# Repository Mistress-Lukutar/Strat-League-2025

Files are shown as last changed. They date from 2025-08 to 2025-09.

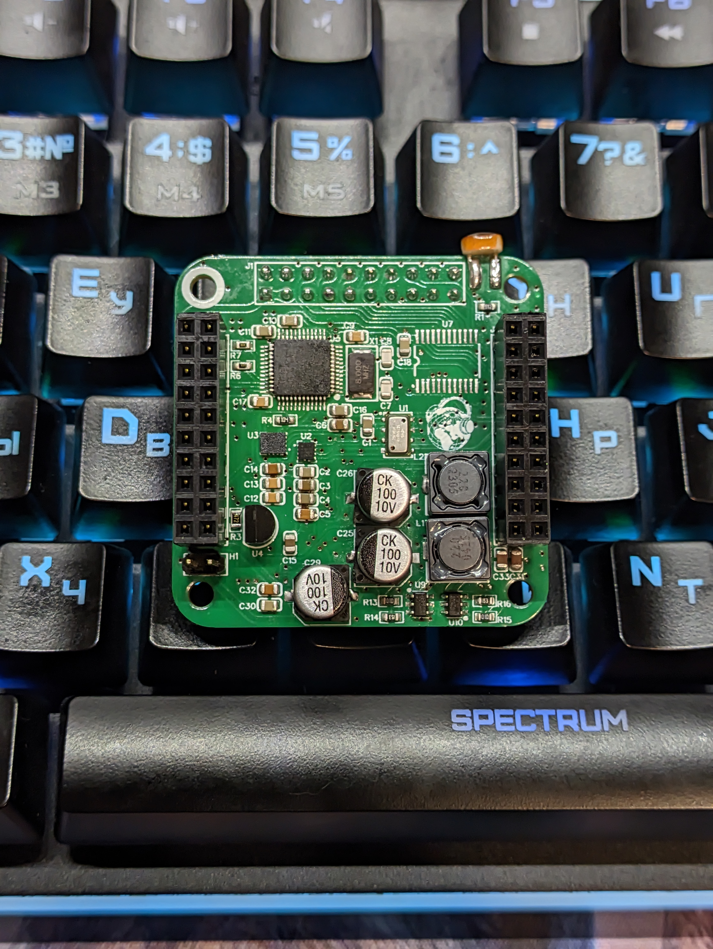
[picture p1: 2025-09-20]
Photos/PCB/IMU.jpg

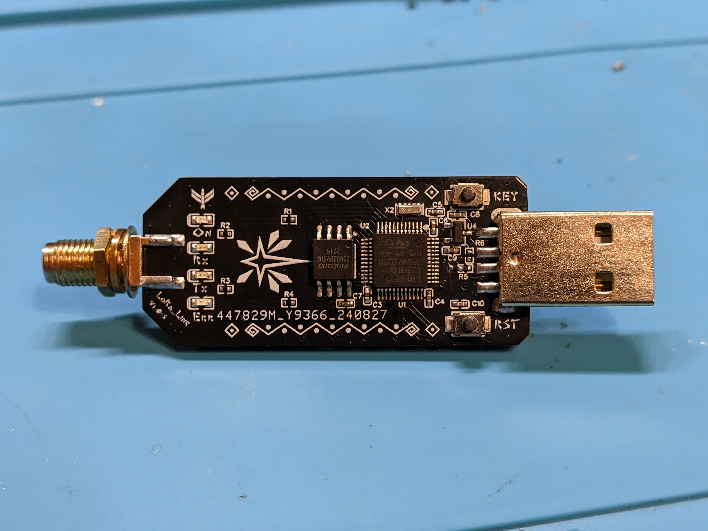
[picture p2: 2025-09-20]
Photos/PCB/LoRa Link.jpg

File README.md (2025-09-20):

# 🚀 Strat-League-2025: Sporadic Team Project

**Команда Sporadic | Курск**

Добро пожаловать в репозиторий стратосферного эксперимента по исследованию эффективности наночастиц в области технологий защиты от космической радиации!

## 📖 О проекте

Наш стратосферный аппарат предназначен для измерения радиационного фона на высоте и оценки защитных свойств различных материалов с наночастицами. Используя четыре сцинтилляционных датчика с разными типами защитных корпусов, мы исследуем, как материалы влияют на регистрацию космической радиации в условиях стратосферы.

### 🎯 Цель исследования

Проверить гипотезу о том, что различные материалы корпусов по-разному защищают от радиационного излучения. Датчик без защиты должен зафиксировать максимальный поток радиации, в то время как защищенные датчики покажут меньшее количество импульсов.

## 👥 Команда Sporadic

Мы — команда энтузиастов из Курска, участвующая во всероссийской программе "Стратосферный спутник". Наш проект объединяет в себе радиоэлектронику, программирование, 3D-моделирование и научные исследования.

> *Забавный факт: весь проект был разработан и реализован чуть больше чем за месяц! От идеи до готового аппарата — рекордные сроки для стратосферного эксперимента* ⚡

### Контакты 
Email: oppp032@gmail.com

Telegram: @the_real_crypto_schizo

## 🛠 Техническая платформа

- **Основа**: платы на базе STM32F4 — надежная и производительная платформа для различных применений
- **Датчики**: сцинтилляционные детекторы частиц, IMU  включающий в себя барометр `MS5611`, 6-DOF `LSM6DS3`, магнитометр `LIS3MDL`
- **Обработка**: плата `RadCounterX4` собственной разработки
- **Связь**: модуль приема телеметрии для ПК `LoRa_Link` собственной разработки, который доказал свою эффективность в нескольких страто- и тропосферных запусках

## 📁 Содержимое репозитория

```
📦 Strat-League-2025/
├── 🏗️ СAD/                 # 3D модели корпуса и креплений
├── ⚡ PCB/                 # Схемы и платы
├── 📚 DOC/                 # Документация, отчеты, презентации
└── 🖼️ Photos/              # Фотографии аппарата и компонентов
```

## 🔗 Связанные репозитории

### Основной код проекта
- **Полная версия**: [CanSat-Regular-HZ](https://github.com/Mistress-Lukutar/CanSat-Regular-HZ/tree/feature/strat2025) - финальный код для стратосферного полета (ветка `/feature/strat2025`)
- **История разработки**: [Project Insights](https://github.com/users/Mistress-Lukutar/projects/1/insights?period=max) - GitHub проект с логами разработки

## 🌟 Особенности проекта

- ✨ **Инновационный подход**: использование наночастиц для радиационной защиты
- 🔬 **Научная ценность**: реальные данные о поведении материалов в стратосфере  
- ⚙️ **Собственные решения**: плата `RadCounterX4` разработана с нуля
- 🚀 **Готовность к полету**: ~~за сутки до запусков~~ полностью протестированный и откалиброванный аппарат

## 🎯 Практическое применение

Результаты исследования могут найти применение в:
- Разработке систем радиационной защиты для космических аппаратов
- Создании защитного оборудования и снаряжения для пилотов
- Исследованиях воздействия космической радиации на материалы
- Образовательных программах по космической технике

## 📊 Результаты

После проведения эксперимента здесь будут представлены:
- Данные с четырех сцинтилляционных датчиков
- Анализ эффективности различных защитных материалов
- Графики изменения радиационного фона по высоте
- Выводы и рекомендации для дальнейших исследований

## 🤝 Участие в программе

Проект выполнен в рамках всероссийской программы "Стратосферный спутник" - уникальной образовательной инициативы, дающей молодым исследователям возможность проводить настоящие научные эксперименты в стратосфере.

---

**Команда Sporadic** • Курск • 2025

*Превращаем идеи в космические эксперименты за рекордные сроки!* 🚀✨

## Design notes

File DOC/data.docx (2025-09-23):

Задание для команд всероссийской программы “Стратосферный спутник”

Начиная с сезона 2025 года на сайте https://stratosputnik.ru/ будет формироваться специальный раздел с информацией об экспериментах всех команд, участвующих в программе. Этот раздел поможет будущим участникам этой и других программ придумывать новые эксперименты, позволит учиться на чужих ошибках и перенимать удачные решения.

Каждая команда обязана подготовить текст для размещения на сайте в соответствии с этим заданием!

Часть 1 (заполняется до запуска)

№ п\п | О чем необходимо написать | Требования к тексту | Ответ
1 | Полное наименование проекта | Без ограничений | Стратосферный аппарат для оценки эффективности наночастиц в области технологий защиты от космической радиации
2 | Явление (технология, объект…), которое исследовала команда | Только наименование явления, технологии, объекта… | Радиационное излучение
3 | Гипотеза: ваше предположение о том, как повлияют условия стратосферы на явление или объект, что будет происходить на аппарате во время запуска | 1 предложение | Четыре сцинтилляционных датчика, поднятые в стратосферу, покажут разное количество импульсов в зависимости от материала корпуса. Датчик без защиты зафиксирует максимальный поток радиации (больше всего импульсов), остальные же покажут меньшее число импульсов благодаря защите.
4 | Методика проведения исследования. Необходимо указать 1) условия проведения эксперимента (на какой высоте, в какое время вы его проводите), 2) последовательность операций на аппарате, благодаря которым происходит эксперимент и измеряются его результаты. | Условия проведения эксперимента - 1 предложение. Алгоритм проведения эксперимента, по 1 предложению на каждую операцию Например: Эксперимент проводится каждые 5000 м, отметки высоты определяется по данным барометра 1. Включение нагрева нихромовой нити с помощью реле 2. Регистрация водорода с помощью датчика MQ-8 3. Выключение нагрева | Эксперимент проводится весь полет начиная от команды «START» до ручного отключения оператором. Последовательность операций следующая Сброс счетчиков ЦИКЛ: Ожидание 100мс (В этот момент счетчики накапливают импульсы от сцинтилляторов) Подача импульса записи показаний счетчика в регистры Сброс счетчиков Последовательное чтение регистров (В этот момент МК имеет данные о количестве частиц, пойманных четырьмя датчиками) Перейти к ЦИКЛ
5 | Список датчиков, электронных модулей и устройств в составе полезной нагрузки (если вы самостоятельно изготавливали платы и электрические модули, кратко опишите принцип их работы) | Список наименований и типов модулей Например: - DS18B20 - термодатчик; - DS1115 - аналогово-цифровой преобразователь | Сцинтилляторы, полученные от партнеров – устройство способное регистрировать заряженные частицы используя сцинтилляционный эффект. Прибор выдает один короткий импульс при регистрации частицы. Модуль RadConterX4 собственной разработки, представляющий собой печатный узел, содержащий 4 счетчика для накопления импульсов от сцинтилляторов, сдвиговый регистр и декодер для выбора счетчика и получения его значения. Исходные файлы представлены в репозитории файлов проекта в папке PCB

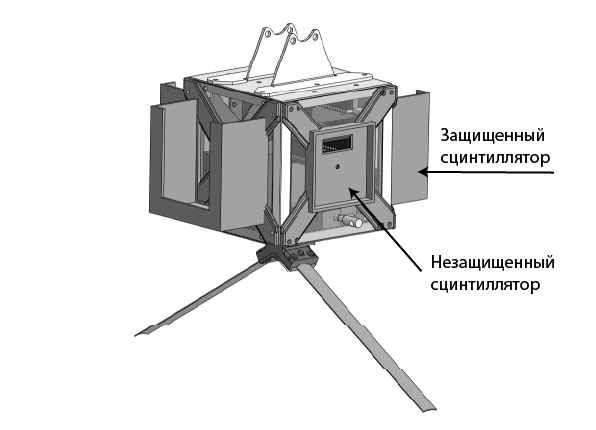
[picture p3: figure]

6 | Схема полезной нагрузки, показывающая принцип ее работы (например, если на аппарате есть механизмы, схема должна объяснять их работу) | Изображение в хорошем разрешении с подписями и, если требуется, кратким пояснением (1-2 предложения) | На рисунке изображены посадочные места под сцинтилляционные датчики – один не защищен материалом с наночастицами, другие – под защитой

Часть 2 (заполняется после запуска и анализа данных)

| О чем необходимо написать | Требования к тексту | Ответ
7 | Какие части ПН правильно работали во время запуска | Не более 60 слов | Работало исправно - Главный контроллер - IMU (Инерциальный измерительный блок) - Сцинтилляторы - Плата захвата RadCounterX4 - Регулятор температуры АКБ - "Черный ящик" (SD и EEPROM)
8 | Какие части ПН неправильно работали во время запуска или не работали. Предполагаемая причина отказа | Не более 60 слов | Возникли проблемы - Связь LoRa: потеряна на высоте около 3 км. - Вероятные причины: несовершенство конструкции антенны и помехи от наземных глушилок на частоте 433 МГц. - GPS: не работал на всём протяжении полёта. - Причина: сильное воздействие наземных глушилок.

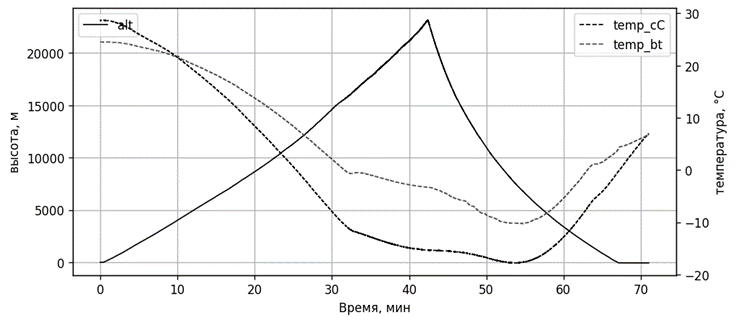
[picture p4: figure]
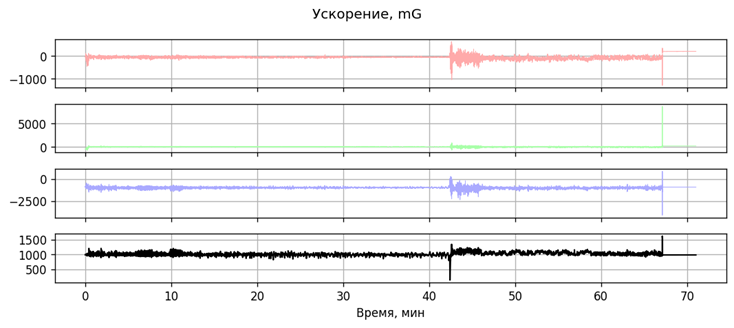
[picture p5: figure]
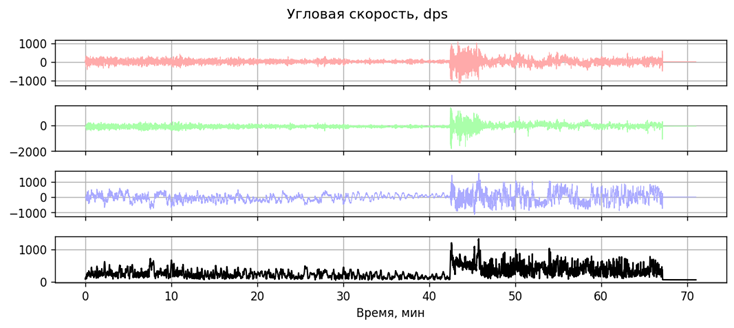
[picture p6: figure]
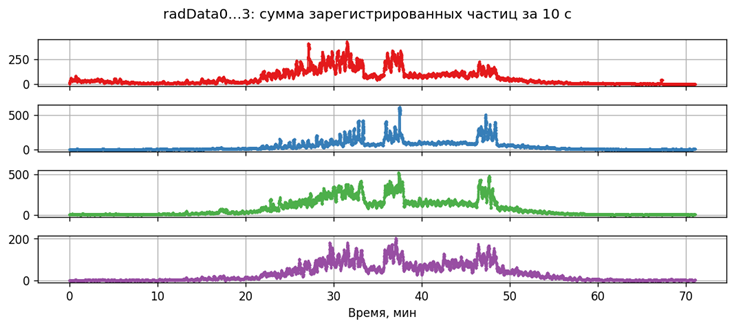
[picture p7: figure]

9 | Результат исследования, научный вывод: подтверждение или опровержение сформулированной ранее гипотезы | Не более 60 слов | Данные полученные бортовой электроникой Temp_cC – температура электроники, temp_bt - температура АКБ Здесь 3 цвета – оси XYZ, черная линия – модуль (усреднен) Экспериментально подтвердили гипотезу – материалы с наночастицами действительно защитили датчики от радиации. Максимальный фон был зарегистрирован датчиком без защиты (канал 2, > 500 событий пиковое значение), минимальный – с защитой с использованием CaO_2 (канал 4, до 200 событий)
10 | Финальный (лётный) программный код | Ссылка на Google/Яндекс Диск с открытым для просмотра доступом! По ссылке должен находиться исходный код в текстовом файле формата “.txt” | GitHub проект с логами разработки: https://github.com/users/Mistress-Lukutar/projects/1/insights?period=max Полный код проекта: https://github.com/Mistress-Lukutar/CanSat-Regular-HZ/tree/feature/strat2025 Репозиторий файлов проекта: https://github.com/Mistress-Lukutar/Strat-League-2025

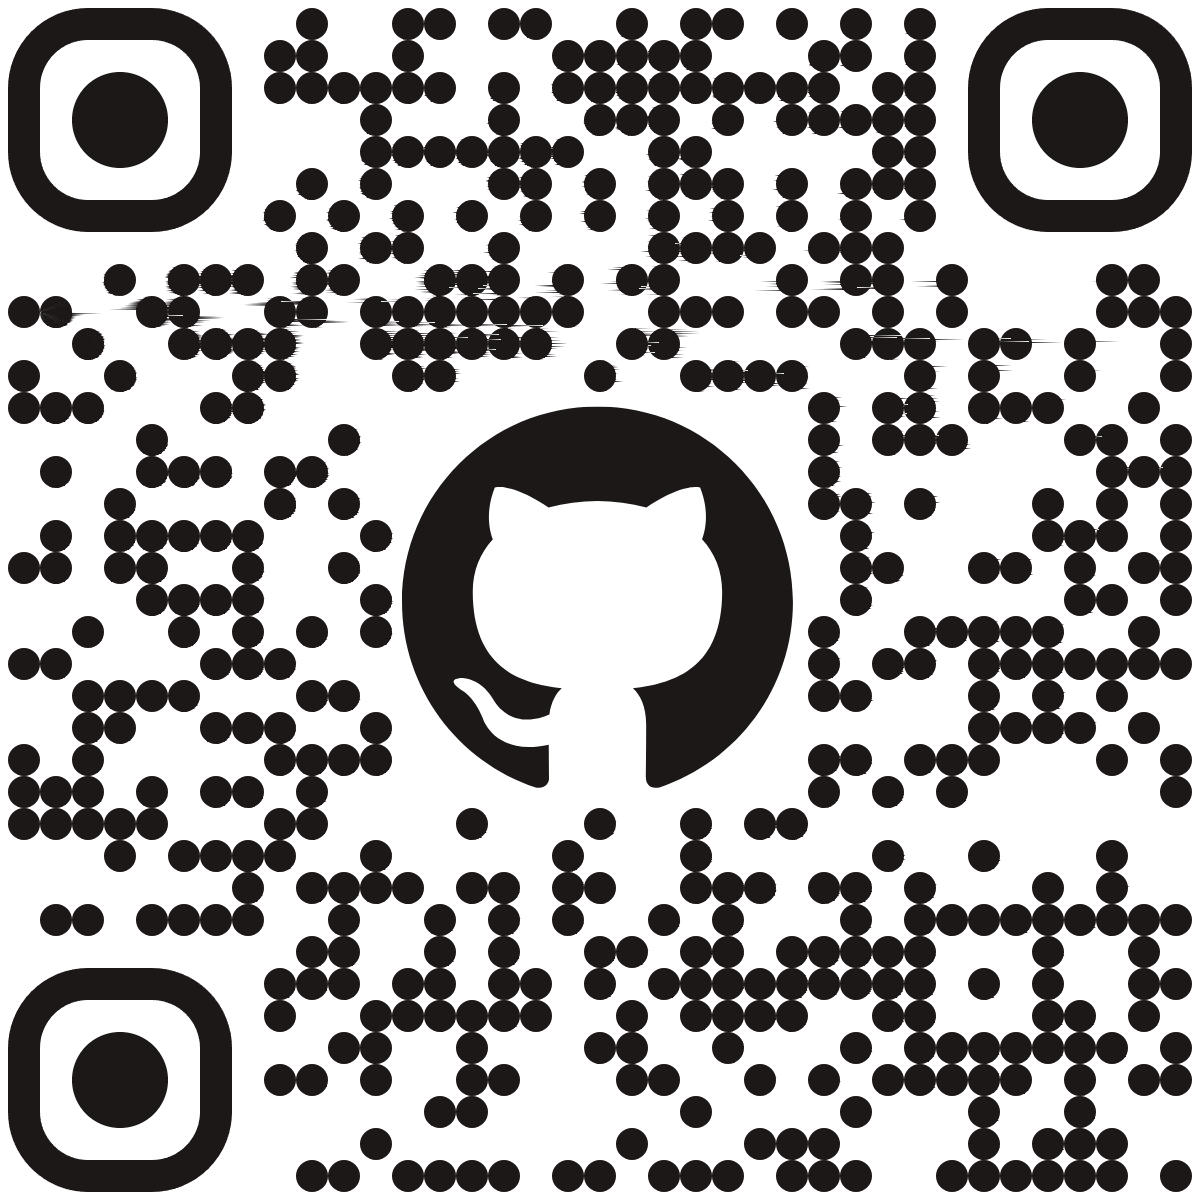
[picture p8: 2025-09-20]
DOC/Flyer/QR.png

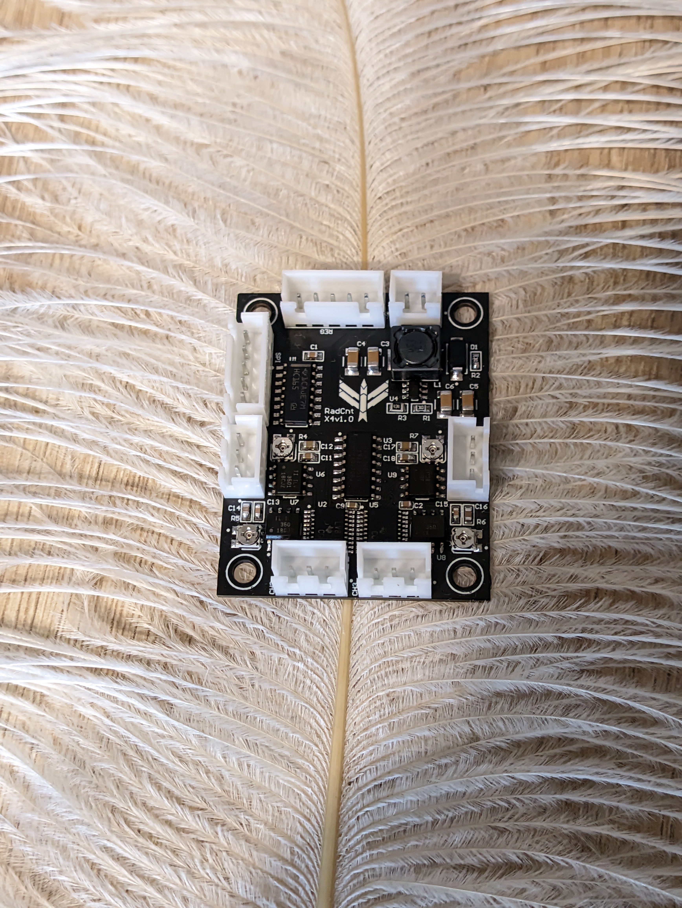
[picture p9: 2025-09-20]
Photos/PCB/RadCounterX4.jpg

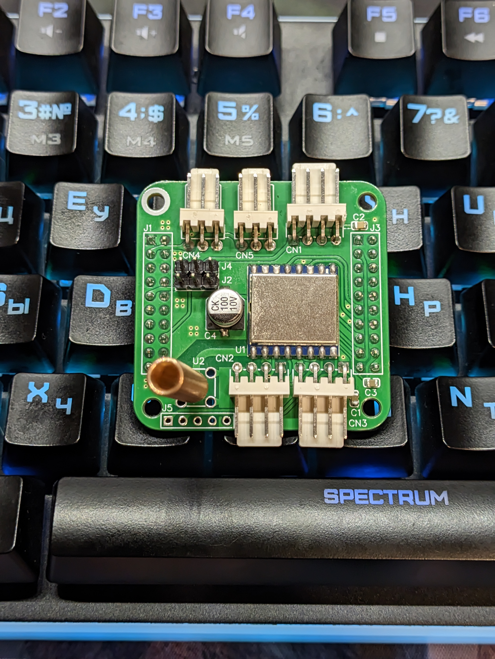
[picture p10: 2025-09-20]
Photos/PCB/Radio.jpg

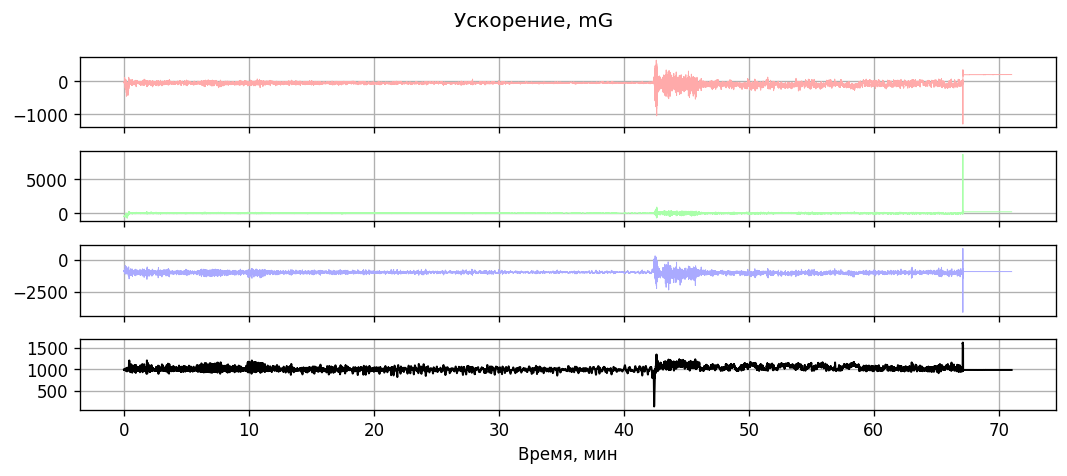
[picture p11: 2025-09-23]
Photos/plots/02_accel_4subplots.png

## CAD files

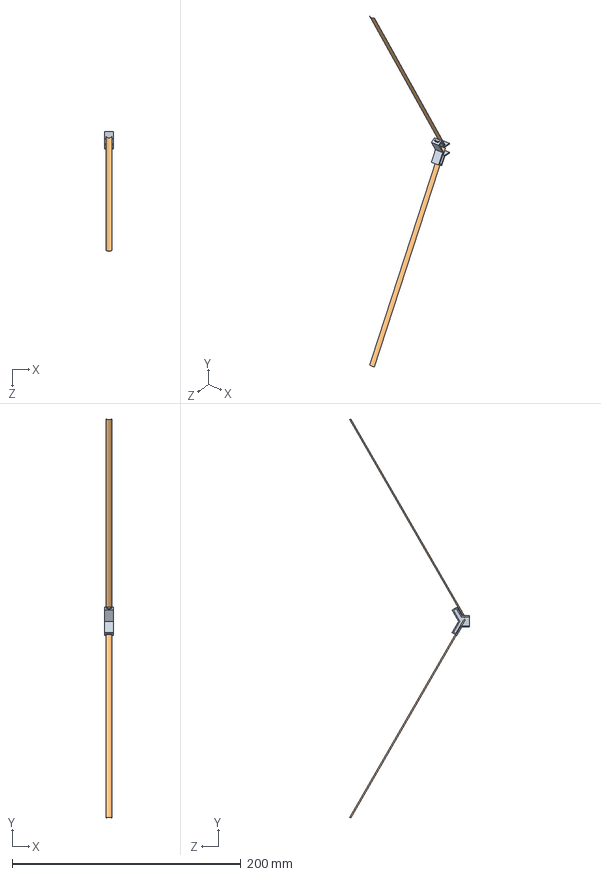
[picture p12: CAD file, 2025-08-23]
CAD/SolidWorks_release/Antenna/Ant.SLDASM
8.00 x 348.9 x 104.6 mm
Element x 2
Holder

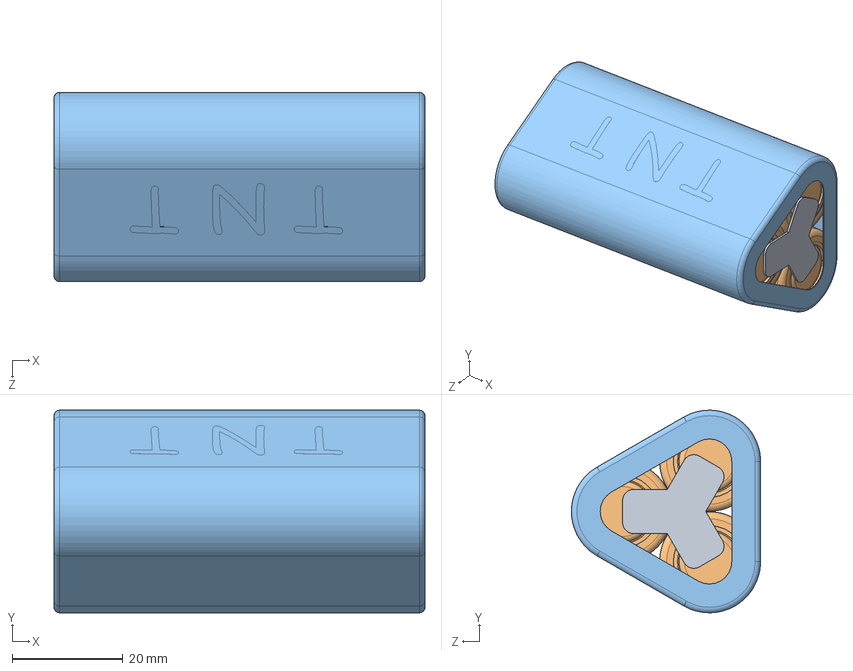
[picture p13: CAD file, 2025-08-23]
CAD/SolidWorks_release/BAT/Battery Pack.SLDASM
67.0 x 36.6 x 34.2 mm
PVC Battery Tube
Generic Li Ion 1850 cell x 3
Contact x 2

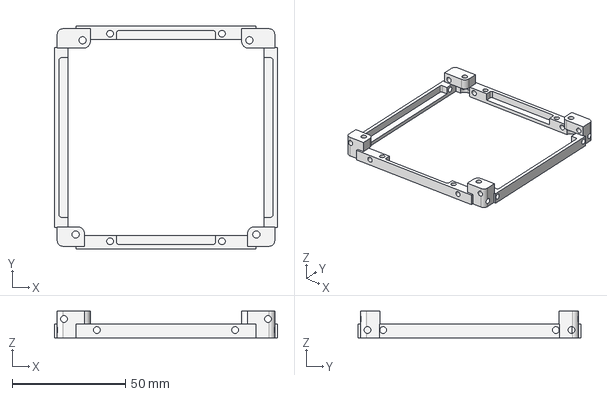
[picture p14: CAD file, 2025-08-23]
CAD/Export/Step/Frame Top.stp
98.4 x 98.4 x 11.7 mm

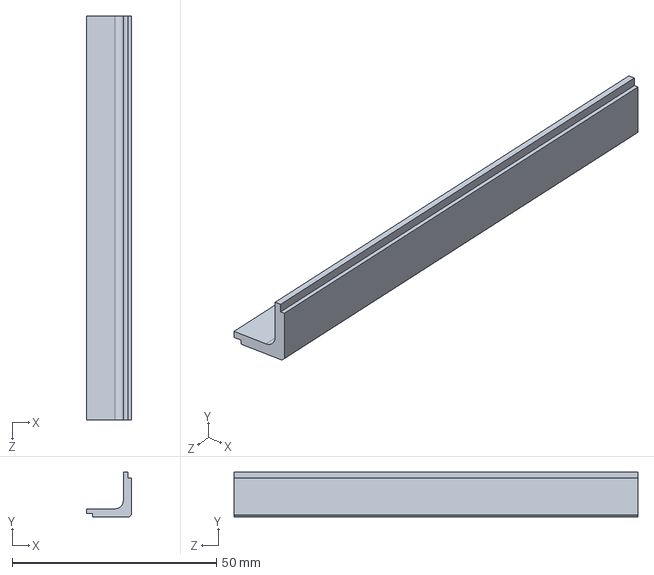
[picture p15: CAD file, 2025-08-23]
CAD/SolidWorks_release/CubeSat/Border.SLDPRT
11.0 x 11.0 x 99.0 mm

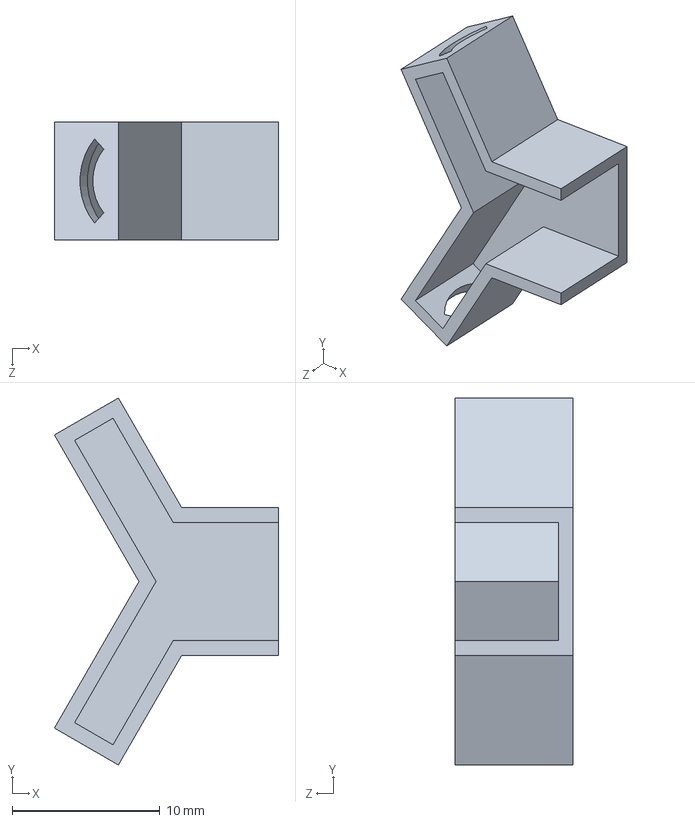
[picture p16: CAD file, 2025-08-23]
CAD/SolidWorks_release/Antenna/Holder.SLDPRT
15.2 x 24.8 x 8.00 mm

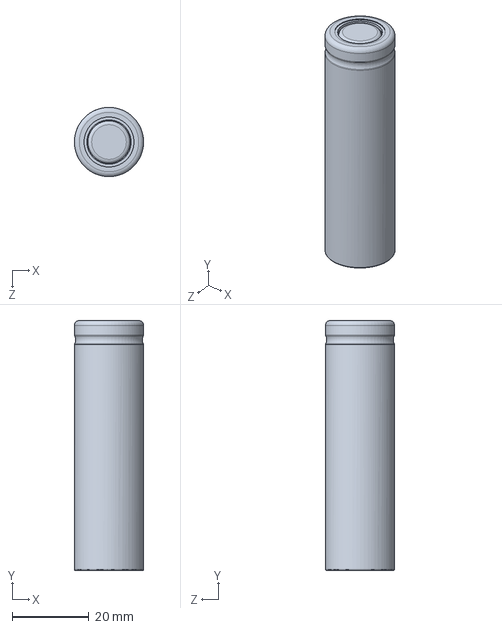
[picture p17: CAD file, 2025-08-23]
CAD/SolidWorks_release/BAT/Generic Li Ion 1850 cell.SLDPRT
18.0 x 65.0 x 18.0 mm

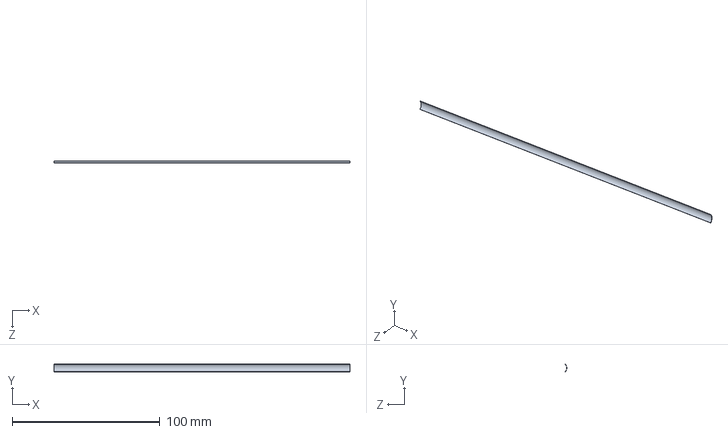
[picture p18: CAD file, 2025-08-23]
CAD/SolidWorks_release/Antenna/Element.SLDPRT
200.0 x 5.28 x 1.20 mm

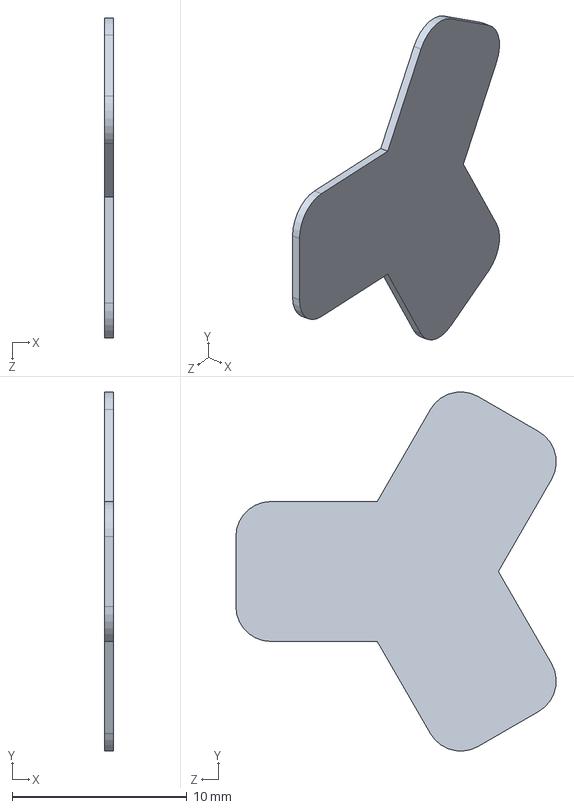
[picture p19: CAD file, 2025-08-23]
CAD/SolidWorks_release/BAT/Contact.SLDPRT
0.5 x 20.5 x 18.3 mm

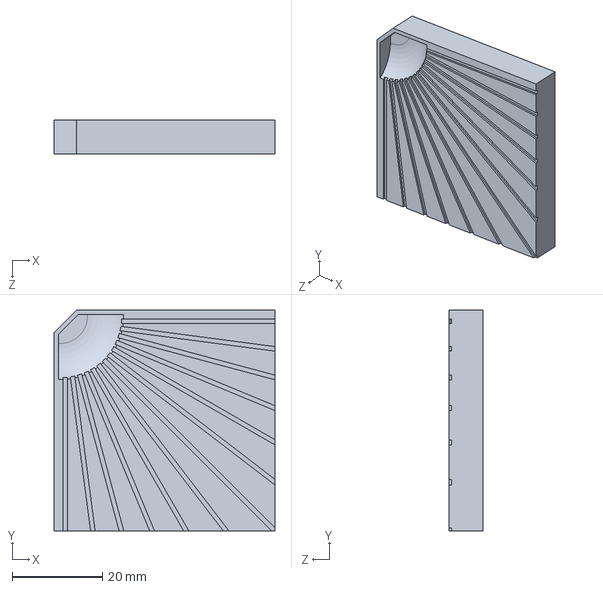
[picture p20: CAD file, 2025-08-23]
CAD/SolidWorks_release/Sensor/Base.SLDPRT
49.0 x 49.0 x 7.50 mm

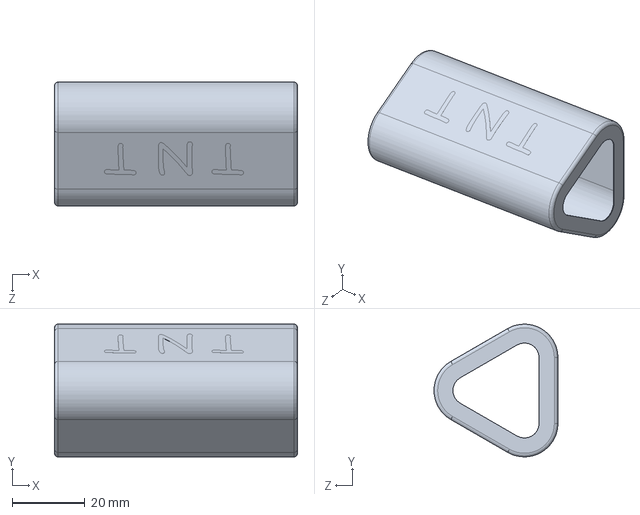
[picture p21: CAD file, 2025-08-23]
CAD/SolidWorks_release/BAT/PVC Battery Tube.SLDPRT
67.0 x 36.6 x 34.2 mm

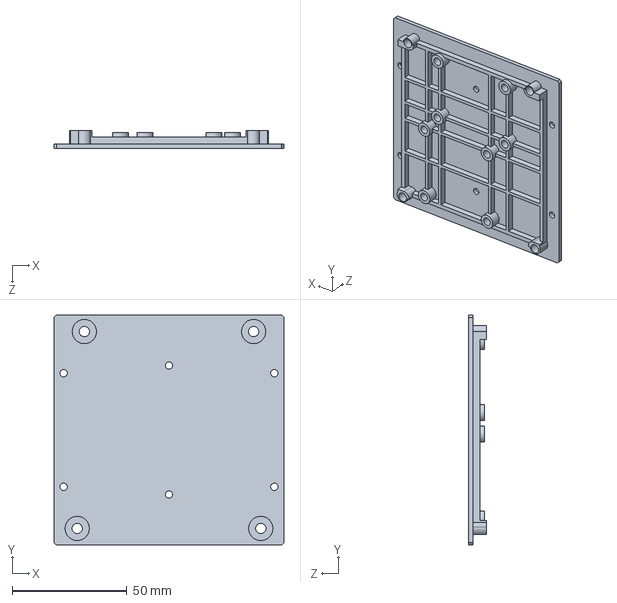
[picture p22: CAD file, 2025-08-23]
CAD/SolidWorks_release/CubeSat/Cover.SLDPRT
100.0 x 100.0 x 7.80 mm

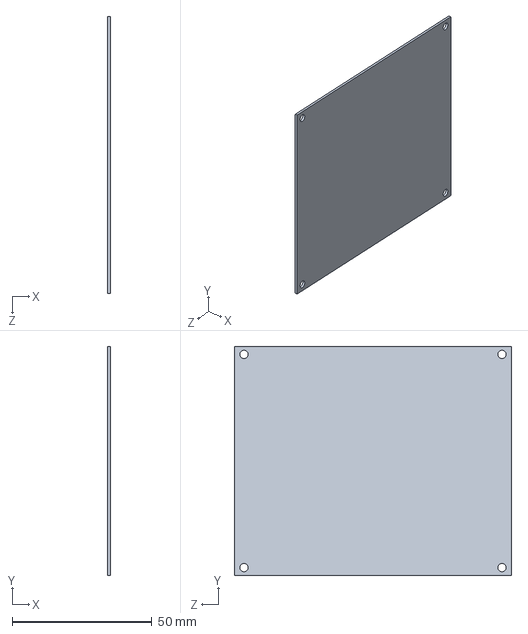
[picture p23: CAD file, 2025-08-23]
CAD/SolidWorks_release/CubeSat/Wall.SLDPRT
1.00 x 82.0 x 99.0 mm

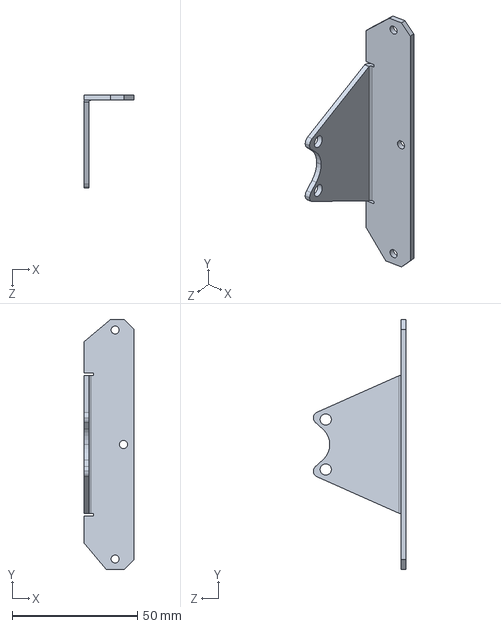
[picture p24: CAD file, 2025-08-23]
CAD/SolidWorks_release/CubeSat/Balloon Mount.SLDPRT
20.0 x 100.0 x 37.0 mm

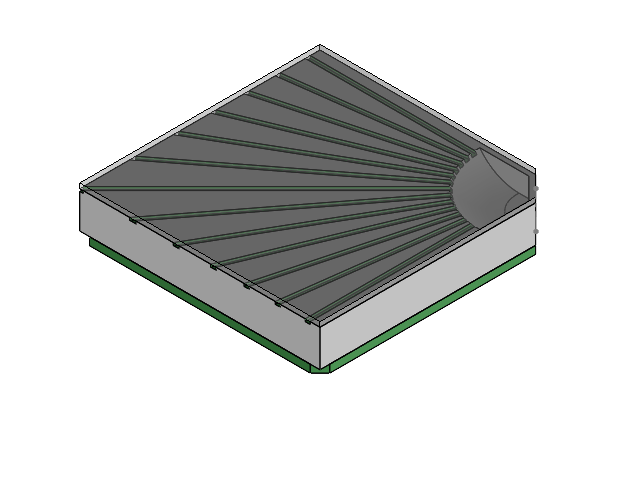
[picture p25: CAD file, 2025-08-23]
CAD/SolidWorks_release/Sensor/Sensor.SLDASM
Base
Glass
PCB
socket button head cap screw_am

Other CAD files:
CAD/SolidWorks_release/Sensor/Glass.SLDPRT
CAD/SolidWorks_release/CubeSat/Frame.SLDPRT
CAD/SolidWorks_release/CubeSat/RHZ Insert.SLDPRT
CAD/SolidWorks_release/Sensor/PCB.SLDPRT
CAD/Archive/Bobyshka_dlya_antenn18_svoya.stp
CAD/Archive/Generic Li Ion 1850 cell.step
CAD/Archive/Korpus_RBL.stp
CAD/Archive/M3 insert nut brass.STEP
CAD/Archive/Sborka_bloka_plat.stp
CAD/Archive/nasha_polnaya_sborka_21.stp
CAD/Export/parasolid/Detal.x_t
CAD/Export/parasolid/bobishka dlya antenn.x_t
CAD/Export/parasolid/dno s akb.x_t
CAD/Export/parasolid/krepesh scintilatora 1.x_t
CAD/Export/parasolid/krepesh scintilatora 2.x_t
CAD/Export/parasolid/krishka s kreplenyem shara.x_t
CAD/Export/parasolid/ugolok 22.x_t
CAD/Export/parasolid/ugolok12.x_t
CAD/SolidWorks_release/CubeSat/M3 insert nut.SLDPRT

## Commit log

2025-07-24 Set up on track DOC & CAD folders
2025-07-24 Updated description in PCB
2025-07-27 added valid CAD folder structure & uploaded archive
2025-07-27 Added step files in archive
    [Bobyshka_dlya_antenn18_svoya.stp, Generic Li Ion 1850 cell.step, Korpus_RBL.stp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]
2025-07-29 добвила 1 версию сборки 1u корпуса и детали к нему
2025-07-30 добавила запчасти для корпуса, а также плату для миссии
2025-08-07 ничо не делала
    [Detal.x_t, bobishka dlya antenn.x_t, dno s akb.x_t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]
2025-08-07 удалила лишние файлы
2025-08-08 добавила последние версии моделей
2025-08-08 added gitignore for temp files & uploaded pcb step
2025-08-09 заменила файлы, на которые ругался компас, но не факт что перестанет он ругаться
2025-08-09 удвлилв лишнее
2025-08-09 добавила кнопку и пиструн
2025-08-09 добавила сборку плат в виде одной детали, чтобы не ломалось
2025-08-09 добавила сборку плат в виде детали, чтобы не ломалось
2025-08-09 Added kompas-3d ocmpatible RadCounterX4 3D PCB
2025-08-09 сделала подставку под платы
2025-08-13 новая версия крепления антенны и кнопки
2025-08-14 кнопка новая версия
2025-08-14 заменила багованные файлы
2025-08-23 Added SolidWorks Assemby & STEP export
    [Ant.SLDASM, Balloon Mount.SLDPRT, Base.SLDPRT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]
2025-09-01 создала все недостающие 3д модели, переделала старые, сделала полную сборку аппарата
    [креёж стинтилятора 2.stp]
2025-09-16 удалила ножки сборки
